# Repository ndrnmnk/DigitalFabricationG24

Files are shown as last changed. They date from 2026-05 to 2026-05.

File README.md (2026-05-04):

# DigitalFabricationG24

This is a repository of the project students of group 24 made during `Digital Fabrication` course in University of Oulu in 2026.

### X3mist
X3mist is a pager based on a Raspberry pi Pico. It uses RFM95w and WiFi radio module for message exchange.  
The messages are encrypted using AES-256-CBC, and the keys are exchanged through IR LED and receiver.

Other features include a 12 button keyboard and a buzzer.

### Implemented:
- AES-256-CBC message encryption
- WiFi message exchange
- IR data exchange (not used for key exchange yet)
- T9-like keyboard layout

### Not implemented:
- Key exchange
- Radio messaging
- Battery
- Mesh mode

This project may or may not be maintained further. If it is, the link will be changed.

## Footage
### Usage example:

### Assembled device:


### Pre-production PCB renders:
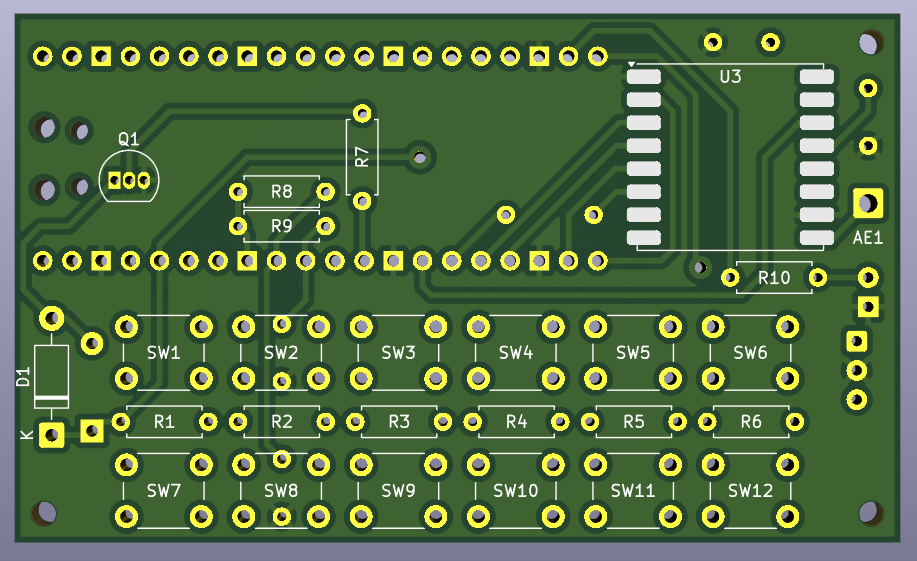
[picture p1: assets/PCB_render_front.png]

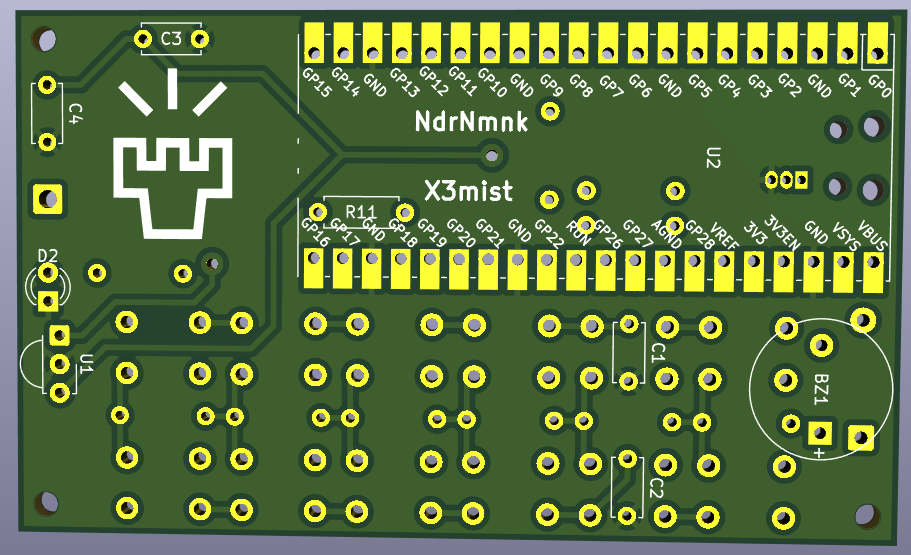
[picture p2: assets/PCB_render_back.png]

### Schematic:
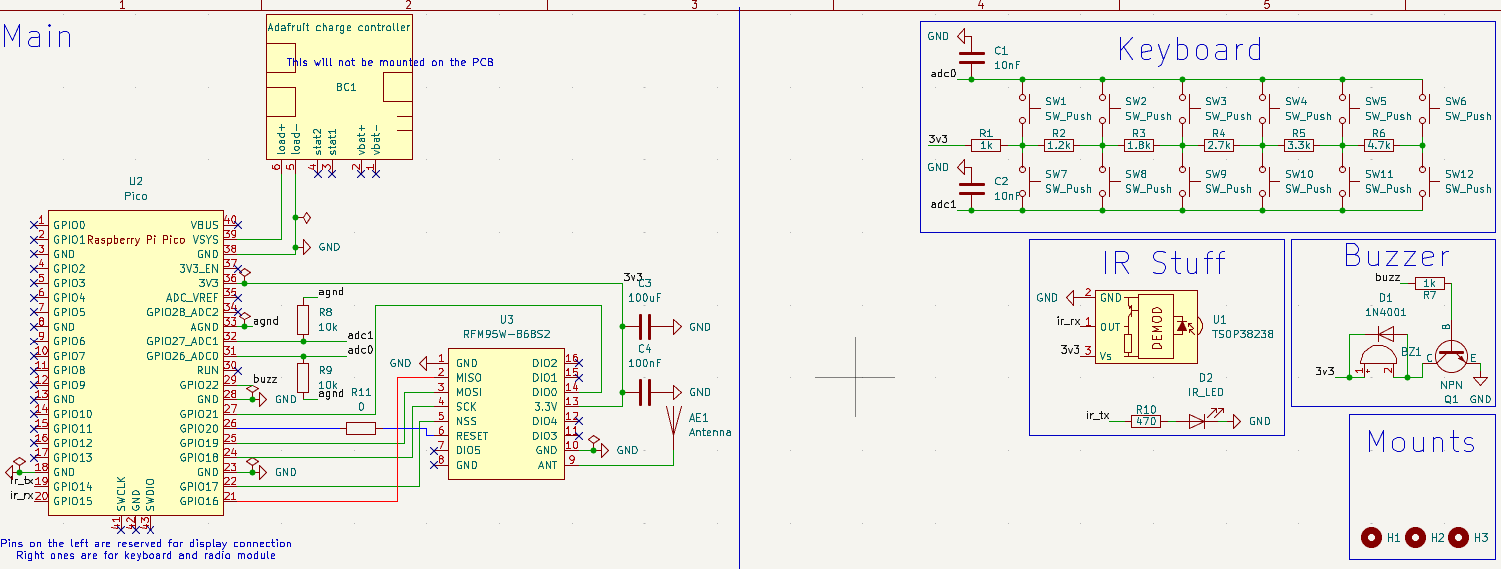
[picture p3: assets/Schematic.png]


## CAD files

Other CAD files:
Fusion_Files/PoDF_A.f3d
Fusion_Files/PoDF_B.f3d

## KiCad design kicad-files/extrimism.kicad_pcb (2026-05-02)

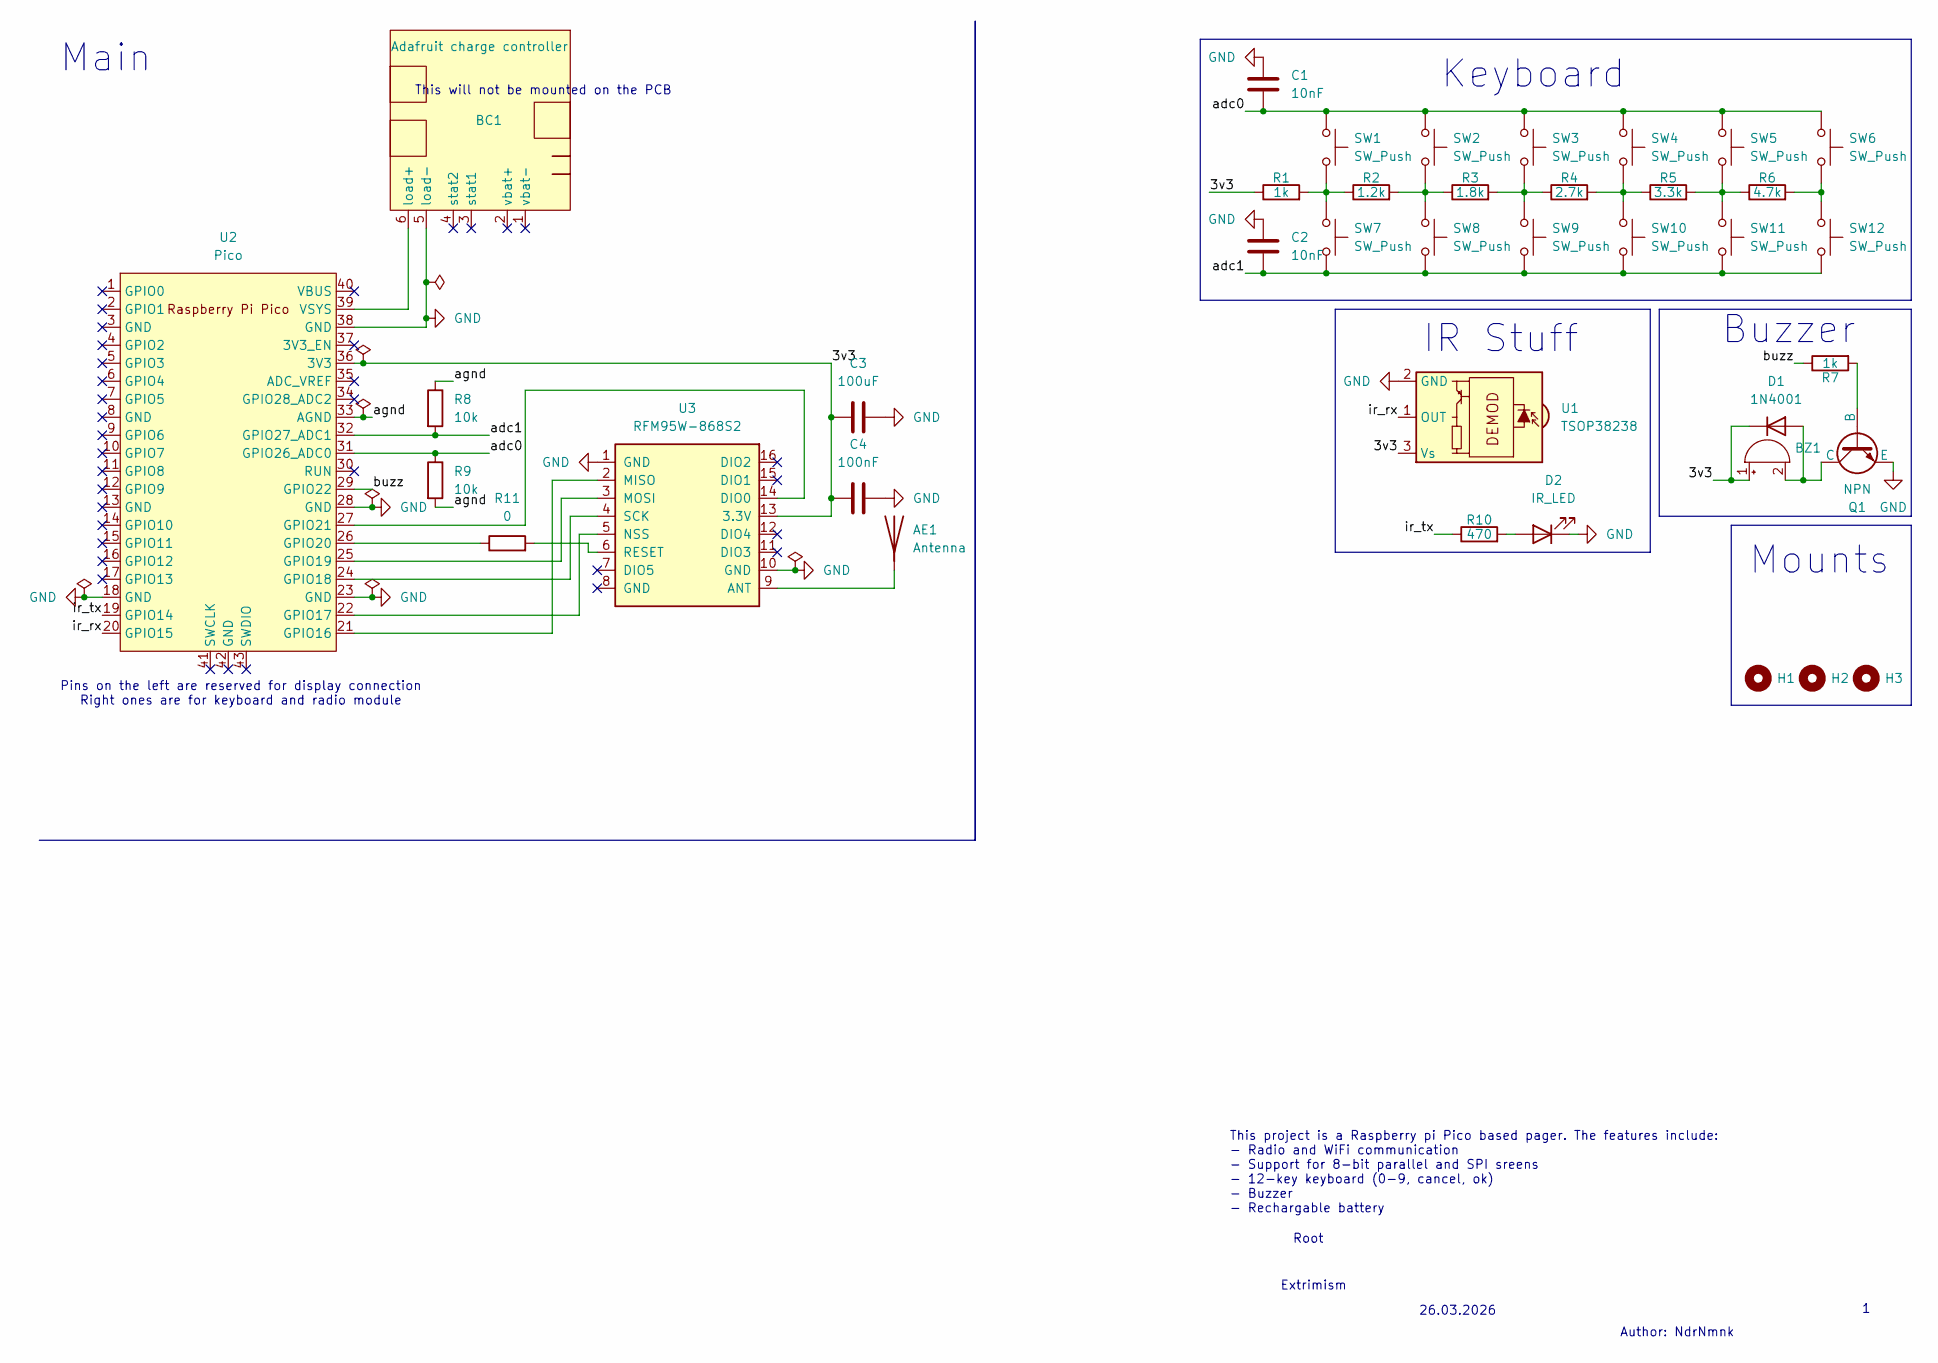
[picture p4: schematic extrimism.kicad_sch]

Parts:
AE1: Antenna; SolderWire-0.75sqmm_1x01_D1.25mm_OD2.3mm
BC1: Adafruit charge controller; extrimism_lib
BZ1: Buzzer; Buzzer_12x9.5RM7.6
C1, C2: 10nF; C_Disc_D5.0mm_W2.5mm_P5.00mm
C3: 100uF; C_Disc_D5.0mm_W2.5mm_P5.00mm
C4: 100nF; C_Disc_D5.0mm_W2.5mm_P5.00mm
D1: 1N4001; D_DO-41_SOD81_P10.16mm_Horizontal
D2: IR_LED; LED_D3.0mm
H1, H2, H3: MountingHole; MountingHole_2.1mm
Q1: NPN; TO-92_Inline
R1, R7: 1k; R_Axial_DIN0207_L6.3mm_D2.5mm_P7.62mm_Horizontal
R2: 1.2k; R_Axial_DIN0207_L6.3mm_D2.5mm_P7.62mm_Horizontal
R3: 1.8k; R_Axial_DIN0207_L6.3mm_D2.5mm_P7.62mm_Horizontal
R4: 2.7k; R_Axial_DIN0207_L6.3mm_D2.5mm_P7.62mm_Horizontal
R5: 3.3k; R_Axial_DIN0207_L6.3mm_D2.5mm_P7.62mm_Horizontal
R6: 4.7k; R_Axial_DIN0207_L6.3mm_D2.5mm_P7.62mm_Horizontal
R8, R9: 10k; R_Axial_DIN0207_L6.3mm_D2.5mm_P7.62mm_Horizontal
R10: 470; R_Axial_DIN0207_L6.3mm_D2.5mm_P7.62mm_Horizontal
R11: 0; R_Axial_DIN0207_L6.3mm_D2.5mm_P7.62mm_Horizontal
SW1, SW2, SW3, SW4, SW5, SW6, SW7, SW8, SW9, SW10, SW11, SW12: SW_Push; SW_PUSH_6mm
U1: TSOP38238; Vishay_MINICAST-3Pin
U2: Pico; RPi_Pico_SMD_TH
U3: RFM95W-868S2; HOPERF_RFM9XW_SMD

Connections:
/3v3: BZ1.1 (+), C3.1, C4.1, D1.1 (K), R1.1, U1.3 (Vs), U2.36 (3V3), U3.13 (3.3V)
/adc0: C1.1, R9.1, SW1.1, SW2.1, SW3.1, SW4.1, SW5.1, SW6.1, U2.31 (GPIO26_ADC0)
/adc1: C2.1, R8.2, SW7.2, SW8.2, SW9.2, SW10.2, SW11.2, SW12.2, U2.32 (GPIO27_ADC1)
/agnd: R8.1, R9.2, U2.33 (AGND)
/buzz: R7.1, U2.29 (GPIO22)
/ir_rx: U1.1 (OUT), U2.20 (GPIO15)
/ir_tx: R10.1, U2.19 (GPIO14)
GND: BC1.5 (load-), C1.2, C2.2, C3.2, C4.2, D2.1 (K), Q1.3 (E), U1.2 (GND), U2.18 (GND), U2.23 (GND), U2.28 (GND), U2.38 (GND), U3.1 (GND), U3.10 (GND)
unnamed: AE1.1 (A), U3.9 (ANT)
unnamed: BC1.6 (load+), U2.39 (VSYS)
unnamed: BZ1.2 (-), D1.2 (A), Q1.1 (C)
unnamed: D2.2 (A), R10.2
unnamed: Q1.2 (B), R7.2
unnamed: R1.2, R2.1, SW1.2, SW7.1
unnamed: R2.2, R3.1, SW2.2, SW8.1
unnamed: R3.2, R4.1, SW3.2, SW9.1
unnamed: R4.2, R5.1, SW4.2, SW10.1
unnamed: R5.2, R6.1, SW5.2, SW11.1
unnamed: R6.2, SW6.2, SW12.1
unnamed: U2.21 (GPIO16), U3.2 (MISO)
unnamed: U2.22 (GPIO17), U3.5 (NSS)
unnamed: U2.24 (GPIO18), U3.4 (SCK)
unnamed: U2.25 (GPIO19), U3.3 (MOSI)
unnamed: R11.1, U2.26 (GPIO20)
unnamed: U2.27 (GPIO21), U3.14 (DIO0)
unnamed: R11.2, U3.6 (RESET)

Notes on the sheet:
Main
IR Stuff
Mounts
This project is a Raspberry pi Pico based pager. The features include: - Radio and WiFi communication - Support for 8-bit parallel and SPI sreens - 12-key keyboard (0-9, cancel, ok) - Buzzer - Rechargable battery
Author: NdrNmnk
Root
Buzzer
Keyboard
Pins on the left are reserved for display connection Right ones are for keyboard and radio module
26.03.2026
Extrimism
This will not be mounted on the PCB

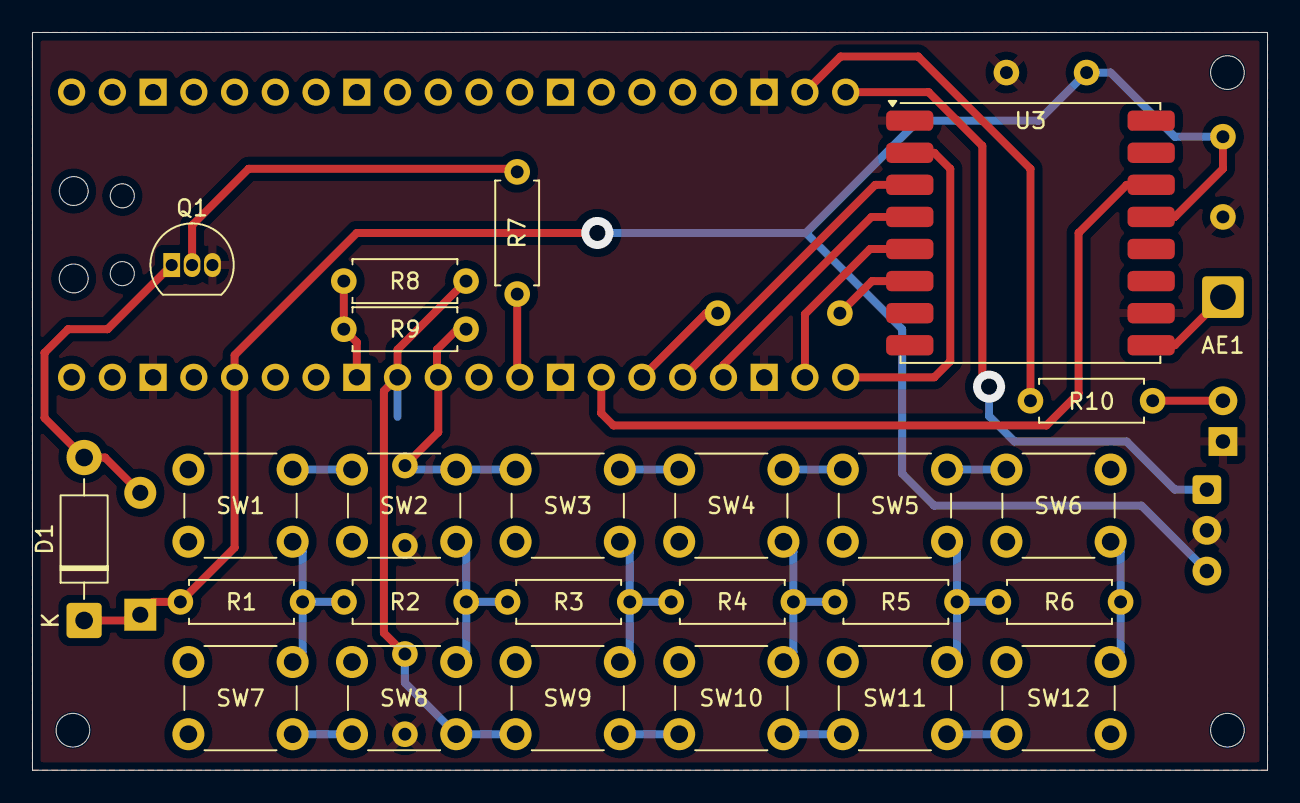
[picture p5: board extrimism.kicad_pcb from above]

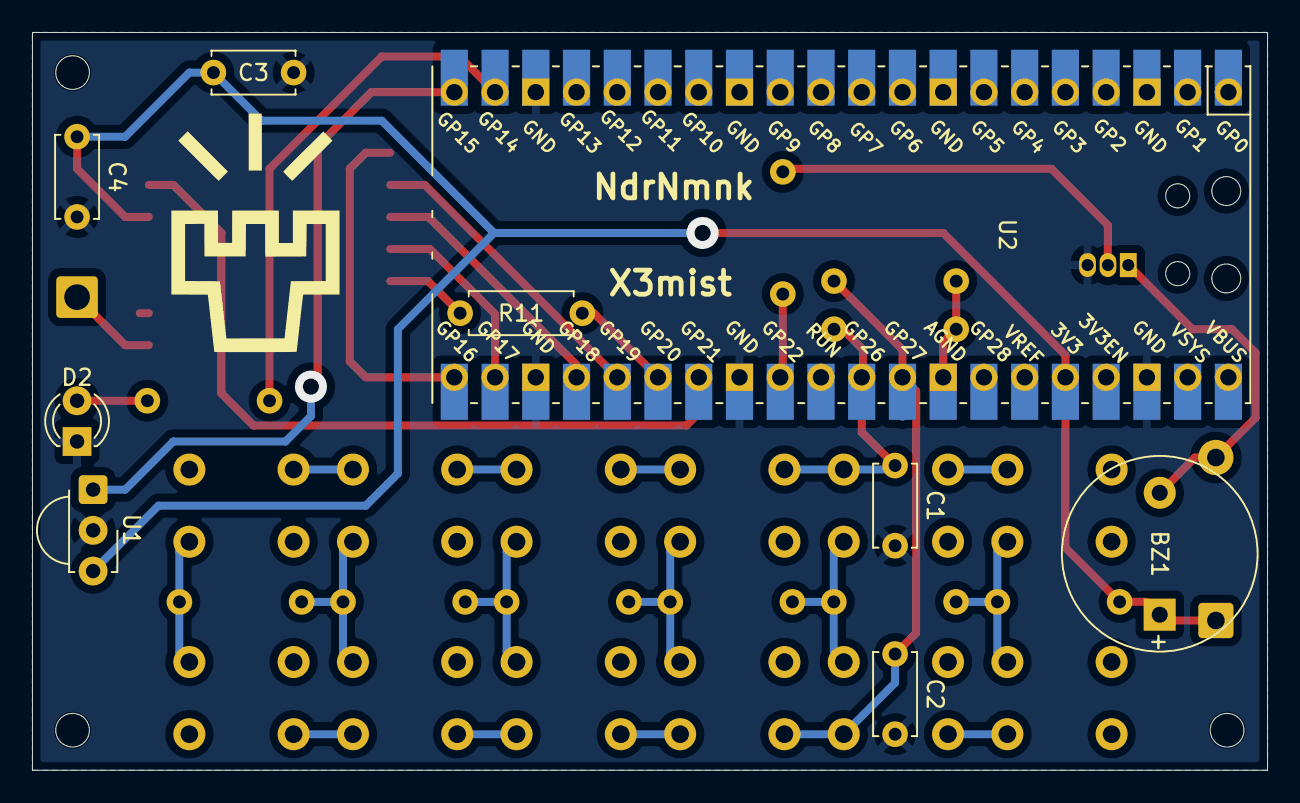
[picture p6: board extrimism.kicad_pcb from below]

Board: 2 copper layers, 77.0 x 46.0 mm, 38 parts (9 on the bottom side), 25 nets.

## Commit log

2026-03-26 added PCB
    [extrimism.kicad_pcb, extrimism.kicad_sch]
2026-04-30 Add files via upload
    PoDF_A is for the E-INK display and PoDF is for the LCD
    [PoDF_A.f3d, PoDF_B.f3d]
2026-05-02 updated PCB design
    [extrimism.kicad_pcb, extrimism.kicad_sch]
2026-05-04 Acrylic backplate for the case
2026-05-04 Update README with features and usage examples
    Added sections for implemented and not implemented features, along with usage examples and images of the assembled device and PCB renders.
